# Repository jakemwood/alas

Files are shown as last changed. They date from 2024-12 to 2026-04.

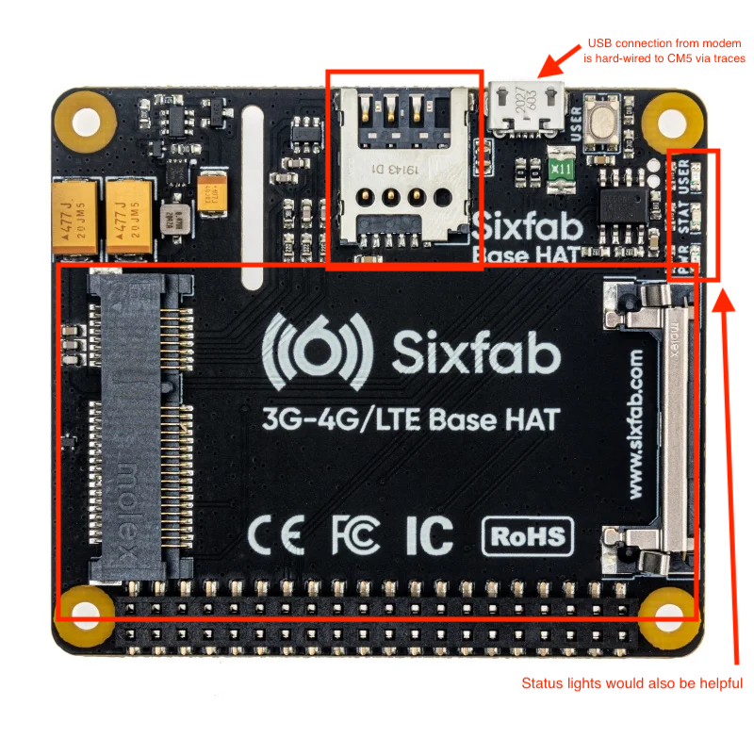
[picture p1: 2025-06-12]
cm5/docs/sixfab diagram.png

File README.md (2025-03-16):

<picture>
  <source media="(prefers-color-scheme: dark)" srcset="docs/logo-white.svg">
  alas logo
</picture>

# ALAS (Automatic Live Audio Streamer)

## Support / Donationware

Commercial support is available for purchase from Ridgeline Radio to support our non-commercial, non-profit radio station.

Stations with budgets over $100,000/year who use ALAS are encouraged to support the project in one of a few ways:

1. Buying the equipment from us
2. Paying monthly subscription fee for the bonded VPN
3. Buying a support package

## About ALAS

ALAS is a hardware/software appliance package that automatically streams and records audio with high reliability.
Whenever audio is present on the sound card input, ALAS will begin streaming and recording. If streaming should stop,
recording will continue, and vice versa. It achieves high straming reliability through the usage of a bonding VPN, with the
designs calling for both a cellular modem and usage of built-in WiFi. ALAS will discontinue streaming and recording after
a configurable period of silence.

## Project Navigation

### alas

The main application, written in Rust, which is deployed onto a Raspberry Pi. It is responsible for:

* Allowing for easy field configuration of the appliance via a WiFi access point
* Managing the WiFi state once configured by the end user
* Manging the cellular state once configured by the end user
* Continuously monitoring input audio signal to determine when audio is being input
* Stream audio to Icecast when audio is present
* Providing a web interface for end users to administer the device
* Ensuring audio traffic is using the appropriate Engarde Wireguard interface

### cad

You'll find FreeCAD and STEP files in this folder for fabricating the rack mountable case.

### docs

You'll find instructions on how to assemble the hardware and user's guide in this folder. Documentation for software
is generally found adjacent to these components.

### frontend

To save bandwidth, a static frontend is available with a configurable backend. The static frontend is found here.
This is distinct from the "deployed frontend," which is used during the initial configuration of the network settings
on the Raspberry Pi.

### infrastructure

This is the Terraform used to create the bonding VPN servers in Microsoft Azure. 

## ALAS Software Components

### alas_lib

alas_lib is meant to serve as the "brains" of the operation. However, there is some serious
separation of concerns issues here, as the main state of the application is actually held in `alas`.

### alas

This is the monolithic application that runs on the Raspberry Pi.

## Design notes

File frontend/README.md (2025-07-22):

# Frontend

This frontend is deployed to a static server (currently https://alas.krdf.org)

It was done this way so the frontend could be quickly loaded, and then only
minimal API payloads are shipped back and forth between the ALAS unit and
the browser.

## Deployment

Currently, deployment happens via git integration to Cloudflare pages.

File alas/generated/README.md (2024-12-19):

these files were generated by...

```shell
# on pi
busctl --system introspect org.freedesktop.NetworkManager /org/freedesktop/NetworkManager/Devices/1 --xml > out.xml
# copy out.xml to mac
scp ridgeline@ridgeline-live.local:/home/ridgeline/out.xml .
zbus-xmlgen file out.xml 
```

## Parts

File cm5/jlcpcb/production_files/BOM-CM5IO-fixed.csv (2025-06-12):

Comment | Designator | Footprint | LCSC | Quantity
2.2K 1% | R16 | R_0402_1005Metric | C114762 | 1
1k | R1,R10 | R_0402_1005Metric | C11702 | 2
LED Green | D2 | LED_0603_1608Metric | C12624 | 1
0.1uF | C1 | C_0603_1608Metric | C14663 | 1
4.7nF | C11 | C_0402_1005Metric | C1518204 | 1
100n | C10,C18,C26,C28,C30,C9 | C_0402_1005Metric | C1525 | 6
15pF | C31,C32 | C_0402 | C1548 | 2
10uF | C12,C13,C22,C23,C25,C27,C29 | C_0402 | C15525 | 7
10u | C14,C15,C16,C17,C2,C4,C6,C7,C8 | C_0805_2012Metric | C15850 | 9
33pF | C19,C20,C21,C5 | C_0603_1608Metric | C1663 | 4
USB3_A | J5 | C168717 | C168717 | 1
0R | R5 | R_0805_2012Metric_Pad1.20x1.40mm_HandSolder | C17477 | 1
0786463001 | J4 | MOLEX_0786463001 | C194938 | 1
AP3441SHE-7B | U8 | DFN-8-1EP_2x2mm_P0.5mm_EP1.05x1.75mm | C2070918 | 1
AP22653W6 | U6 | SOT-23-6 | C212302 | 1
15K | R19 | R_0603_1608Metric | C22809 | 1
LED Red | D1,D3,D6 | LED_0603_1608Metric | C2286 | 3
330 | R2,R3 | R_0603_1608Metric | C23138 | 2
22R | R13,R17,R18 | R_0603_1608Metric | C23345 | 3
15K 1% | R12 | R_0402_1005Metric | C269387 | 1
67910-5700 | J1 | MOLEX_67910-5700 | C277606 | 1
10K 1% | R15 | R_0402_1005Metric | C2906861 | 1
Conn_01x03 | J3,J6 | Molex_Micro-Fit_3.0_43650-0315_1x03_P3.00mm_Vertical | C293546 | 2
1x4 | J2,J7 | CONN_SD-43650-006_04_MOL 1x4 | C293547 | 2
Crystal (24.576MHz) | Y1 | S47SMD | C2975364 | 1
~ | MC1 | 480994000 | C492353 | 1
JST_SHBM04B-SRSS-TB | J14 | JST_SH_BM04B-SRSS-TB_1x04-1MP_P1.00mm_Vertical | C495539 | 1
74LVC1G07SE-7 | U5 | SOT-353_SC-70-5 | C5138996 | 1
2.2uH | L1 | L_Bourns_SRP7028A_7.3x6.6mm | C5189746 | 1
1uF | C24 | C_0402 | C52923 | 1
PCM1863DBT | U1 | DBT30_TEX | C529569 | 1
DALC208SC6 | CR1 | SOT23-6L | C54343 | 1
100K 1% | R14 | R_0402_1005Metric | C60491 | 1
ComputeModule5-CM5 | Module1 | Raspberry-Pi-5-Compute-Module | C6782225 | 2
100uF | C3 | CP_EIA-7343-31_Kemet-D | C72489 | 1

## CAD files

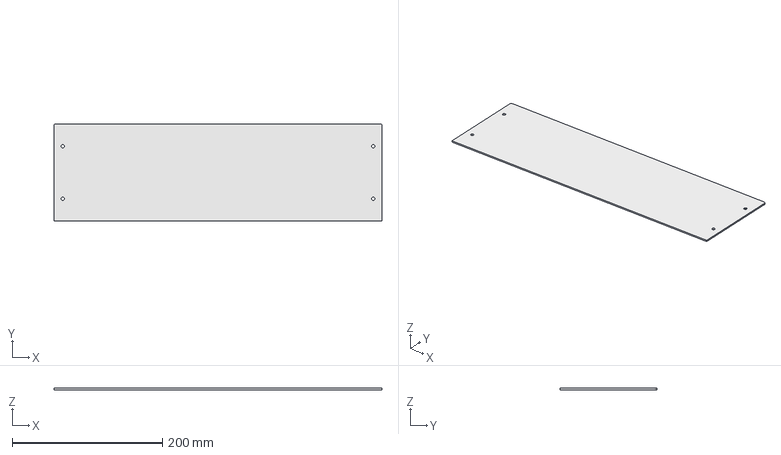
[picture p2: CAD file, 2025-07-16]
cad/Alas-Top.step
436.8 x 129.5 x 2.03 mm

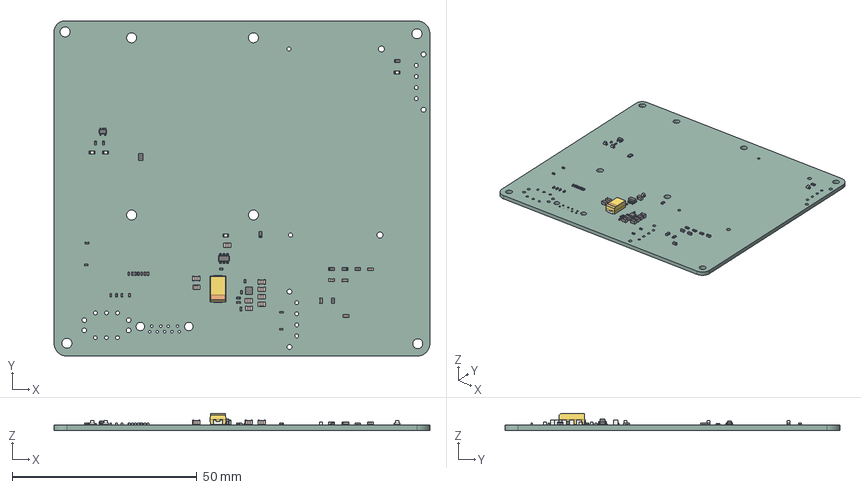
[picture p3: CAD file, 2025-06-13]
cm5/CM5IO.step
101.9 x 90.8 x 4.70 mm
R_0402_1005Metric x 6
LED_0603_1608Metric x 4
SOT-353_SC-70-5
R_0805_2012Metric
DFN-8-1EP_2x2mm_P0.5mm_EP1.05x1.75mm
C_0805_2012Metric x 9
C_0402_1005Metric x 4
C_0402 x 13
C_0603_1608Metric x 5
R_0603_1608Metric x 6
CP_EIA-7343-31_Kemet-D
SOT-23-6
CM5IO_PCB

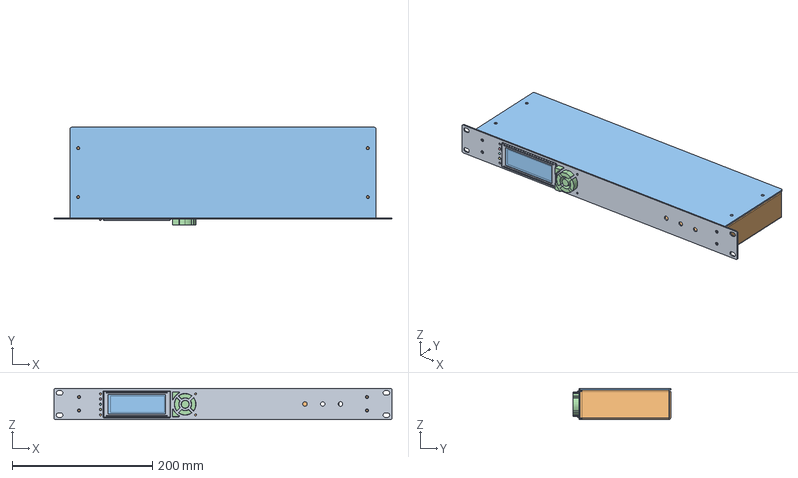
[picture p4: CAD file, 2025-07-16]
cad/Alas.FCStd
482.6 x 139.3 x 44.5 mm
Rack Face
Bottom
Top
GLK PCB_1
JUSBMB-V-TH_1
171825-4 (Alt Power)
Bezzel_1
Bezzel_002
Bezzel_003
2x12 RA Header_1
Glass_1
38mm 7T Keypad_1
LED_1
PCB_1
LED_002
LED_003
2x7 RA Header_1

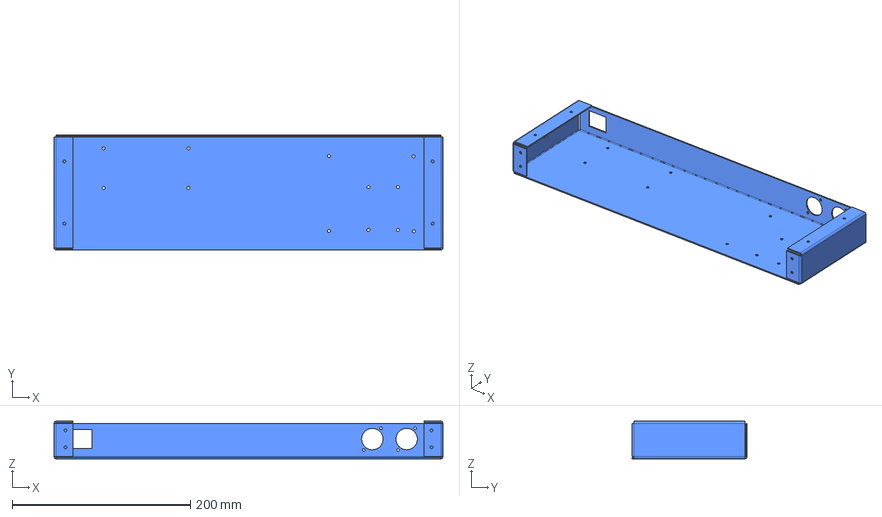
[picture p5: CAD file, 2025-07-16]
cad/Alas-Bottom.step
436.8 x 129.5 x 42.4 mm

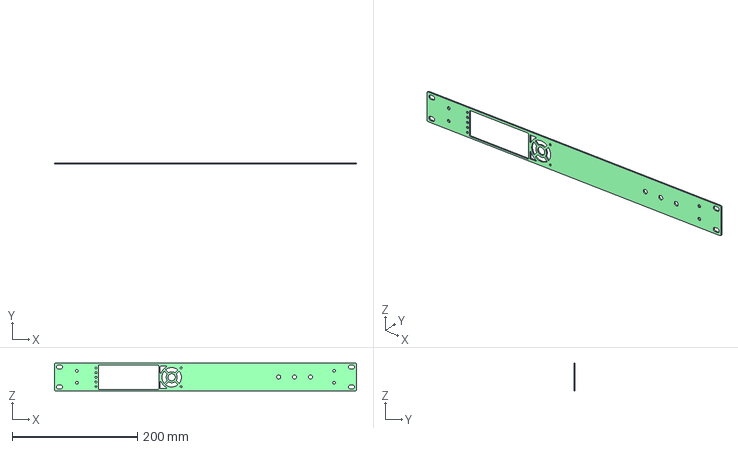
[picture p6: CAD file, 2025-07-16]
cad/Alas-Rack Face.step
482.6 x 1.88 x 44.5 mm

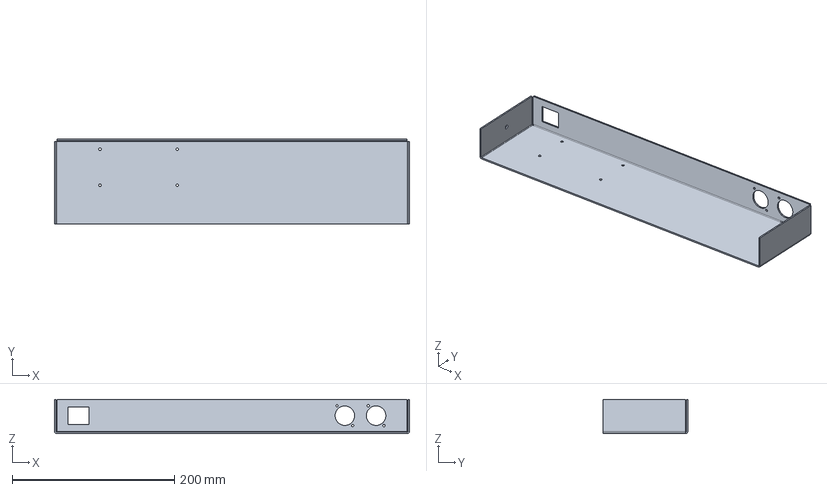
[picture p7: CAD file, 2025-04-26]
cad/New Top.FCStd
437.5 x 104.5 x 42.4 mm

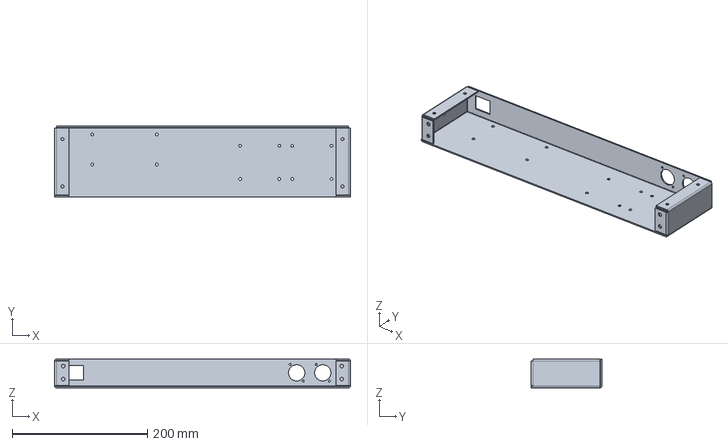
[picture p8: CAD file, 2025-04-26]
cad/Multipart - Flat.FCStd
437.1 x 104.2 x 42.4 mm

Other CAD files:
cad/v0.FCStd

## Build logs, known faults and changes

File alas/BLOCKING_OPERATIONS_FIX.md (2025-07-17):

# Blocking Operations Fix Analysis

## Issue Fixed
The ALSA POLLERR when running both `start_icecast_thread` and `start_file_save_thread` was caused by blocking operations in the audio callback (`handle_samples` function).

## Root Cause
Audio callbacks must be real-time safe and cannot block. The following blocking operations in `handle_samples` were causing ALSA timeouts:
- `state.blocking_read().clone()` at line ~420
- `state.blocking_write()` at lines ~432 and ~445

## Applied Fix
Replaced blocking operations with non-blocking alternatives:

```rust
// Before:
let read_state = {
    state.blocking_read().clone()
};

// After:
let read_state = match state.try_read() {
    Ok(guard) => guard.clone(),
    Err(_) => return, // Skip if can't acquire lock
};

// Before:
let mut state = state.blocking_write();
(*state).is_audio_present = true;

// After:
if let Ok(mut state) = state.try_write() {
    (*state).is_audio_present = true;
}
```

## Remaining Blocking Operations
Found 6 additional blocking operations in the Icecast thread that could be optimized:

### 1. Streaming Status Updates (lines 282-289)
```rust
// Current:
if !state.blocking_read().is_streaming {
    let mut mutable_state = state.blocking_write();
    mutable_state.is_streaming = true;
    let _ = message_bus.send(AlasMessage::StreamingStarted);
}

// Suggested fix:
if let Ok(read_state) = state.try_read() {
    if !read_state.is_streaming {
        drop(read_state);
        if let Ok(mut mutable_state) = state.try_write() {
            mutable_state.is_streaming = true;
            let _ = message_bus.send(AlasMessage::StreamingStarted);
        }
    }
}
```

### 2. Error Handling (lines 289-292)
```rust
// Current:
let mut mutable_state = state.blocking_write();
mutable_state.is_streaming = false;
let _ = message_bus.send(AlasMessage::StreamingStopped);

// Suggested fix:
if let Ok(mut mutable_state) = state.try_write() {
    mutable_state.is_streaming = false;
    let _ = message_bus.send(AlasMessage::StreamingStopped);
}
```

### 3. Loop Cleanup (lines 312-315)
```rust
// Current:
let mut mutable_state = state.blocking_write();
mutable_state.is_streaming = false;
let _ = message_bus.send(AlasMessage::StreamingStopped);

// Suggested fix:
if let Ok(mut mutable_state) = state.try_write() {
    mutable_state.is_streaming = false;
    let _ = message_bus.send(AlasMessage::StreamingStopped);
}
```

### 4. Thread Exit Cleanup (lines 320-322)
```rust
// Current:
let mut mutable_state = state.blocking_write();
mutable_state.is_streaming = false;
let _ = message_bus.send(AlasMessage::StreamingStopped);

// Suggested fix:
if let Ok(mut mutable_state) = state.try_write() {
    mutable_state.is_streaming = false;
    let _ = message_bus.send(AlasMessage::StreamingStopped);
}
```

### 5. Icecast Connection Setup (line 372)
```rust
// Current:
let state = state.blocking_read();

// Suggested fix:
let state = match state.try_read() {
    Ok(guard) => guard,
    Err(_) => {
        std::thread::sleep(std::time::Duration::from_millis(10));
        continue; // Retry connection attempt
    }
};
```

## Priority
- **Critical (FIXED)**: Audio callback blocking operations - these caused the ALSA POLLERR
- **Medium**: Icecast thread blocking operations - these could cause lock contention but are less critical

## Notes
The audio callback fix was essential for real-time audio processing. The remaining fixes are optimizations that would improve overall system responsiveness but are not critical for basic functionality.

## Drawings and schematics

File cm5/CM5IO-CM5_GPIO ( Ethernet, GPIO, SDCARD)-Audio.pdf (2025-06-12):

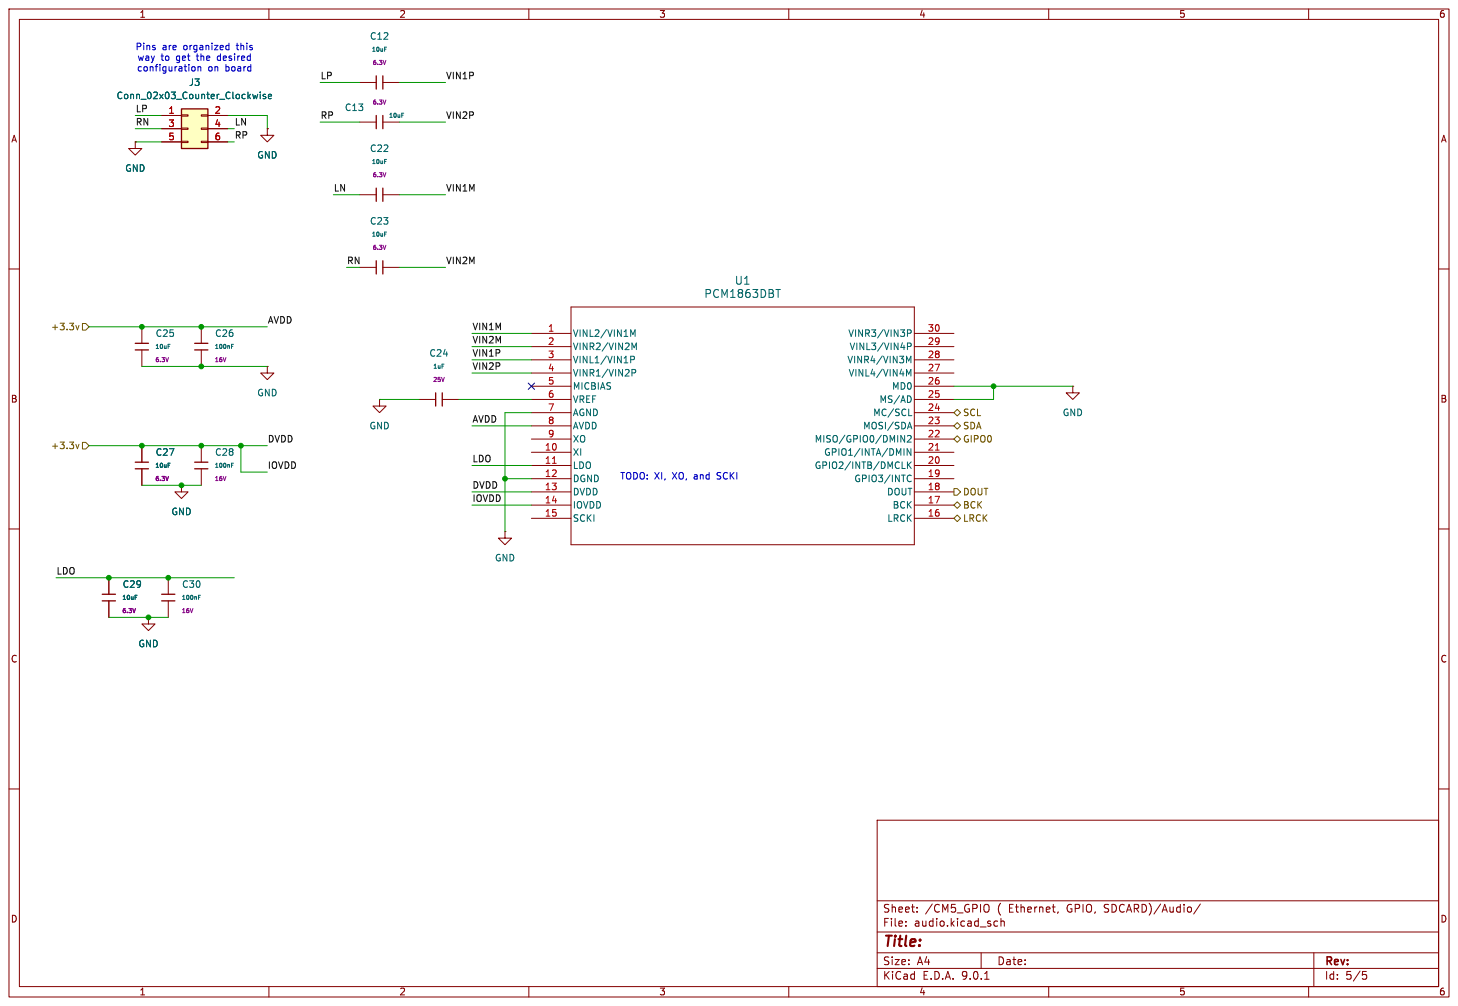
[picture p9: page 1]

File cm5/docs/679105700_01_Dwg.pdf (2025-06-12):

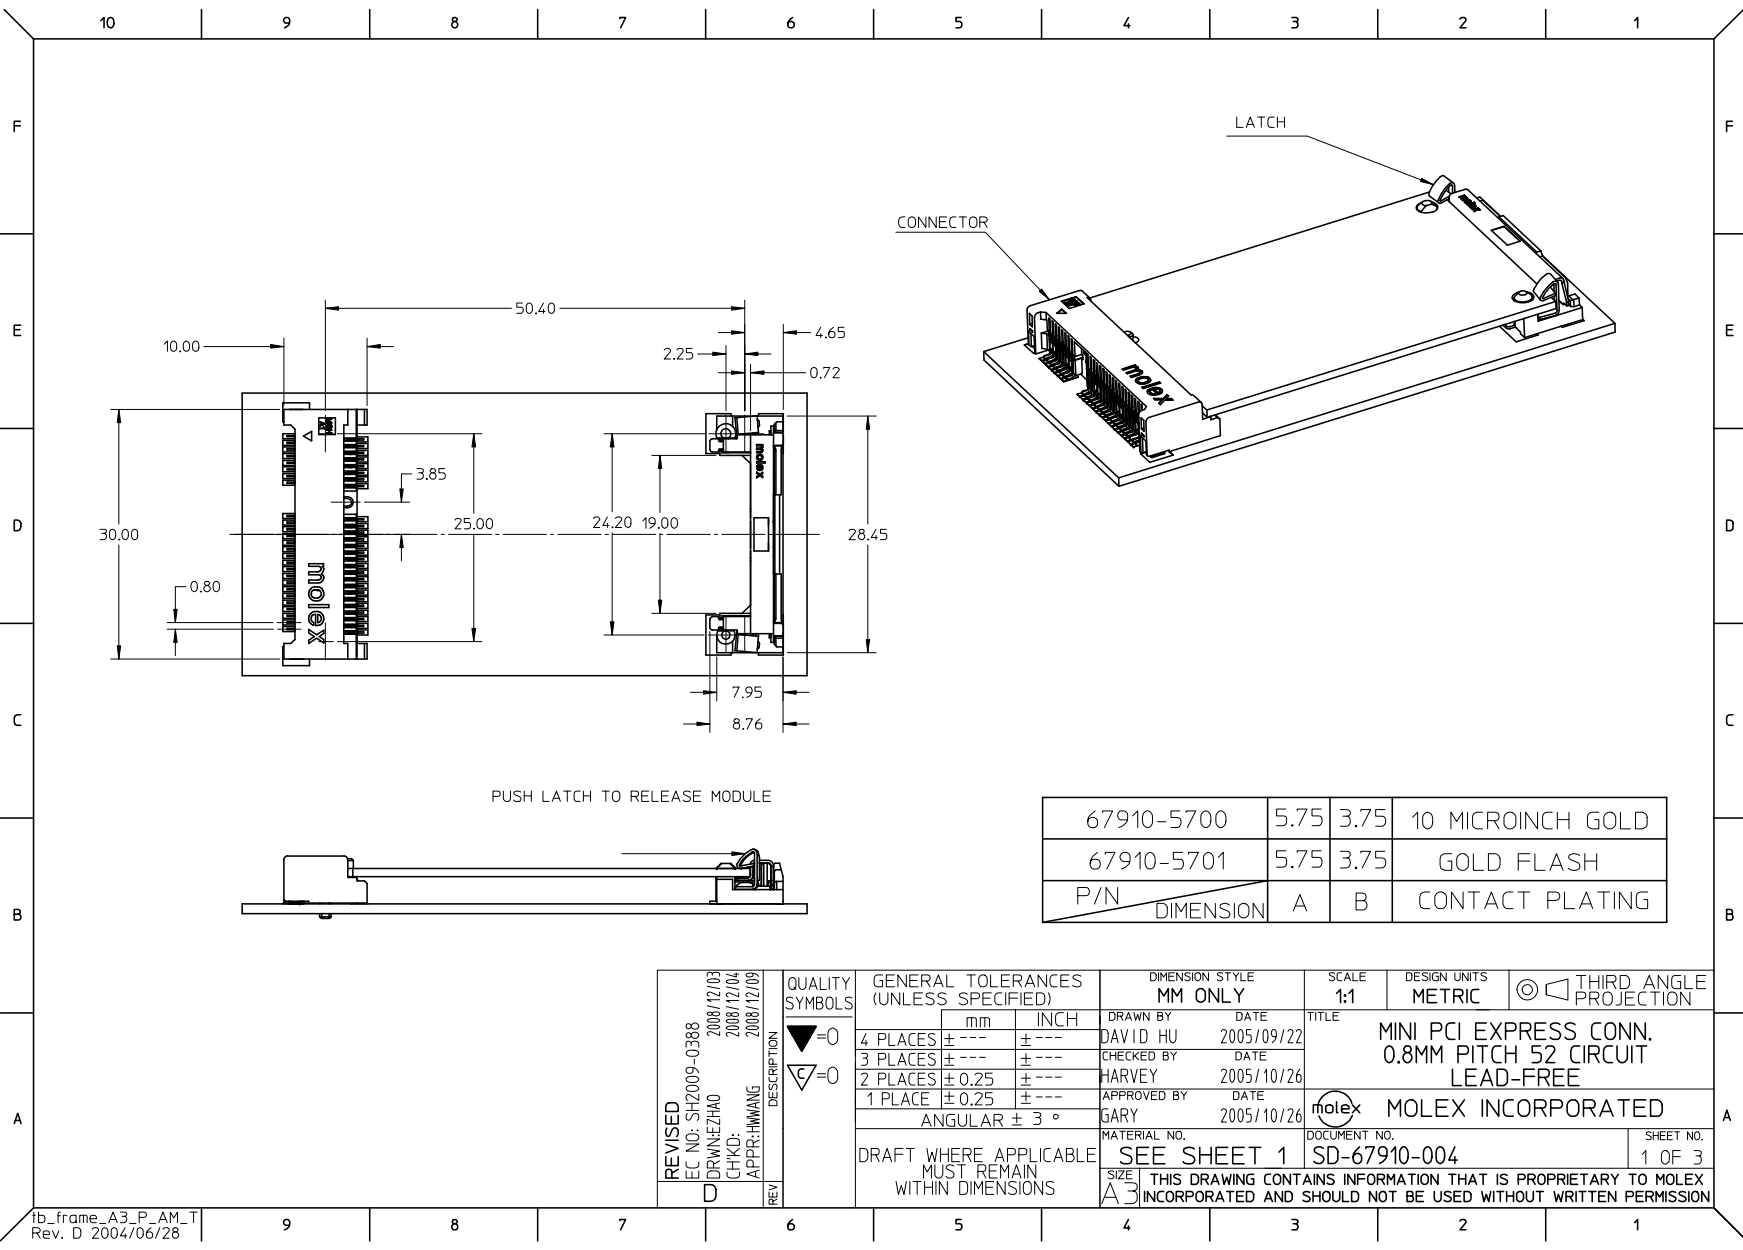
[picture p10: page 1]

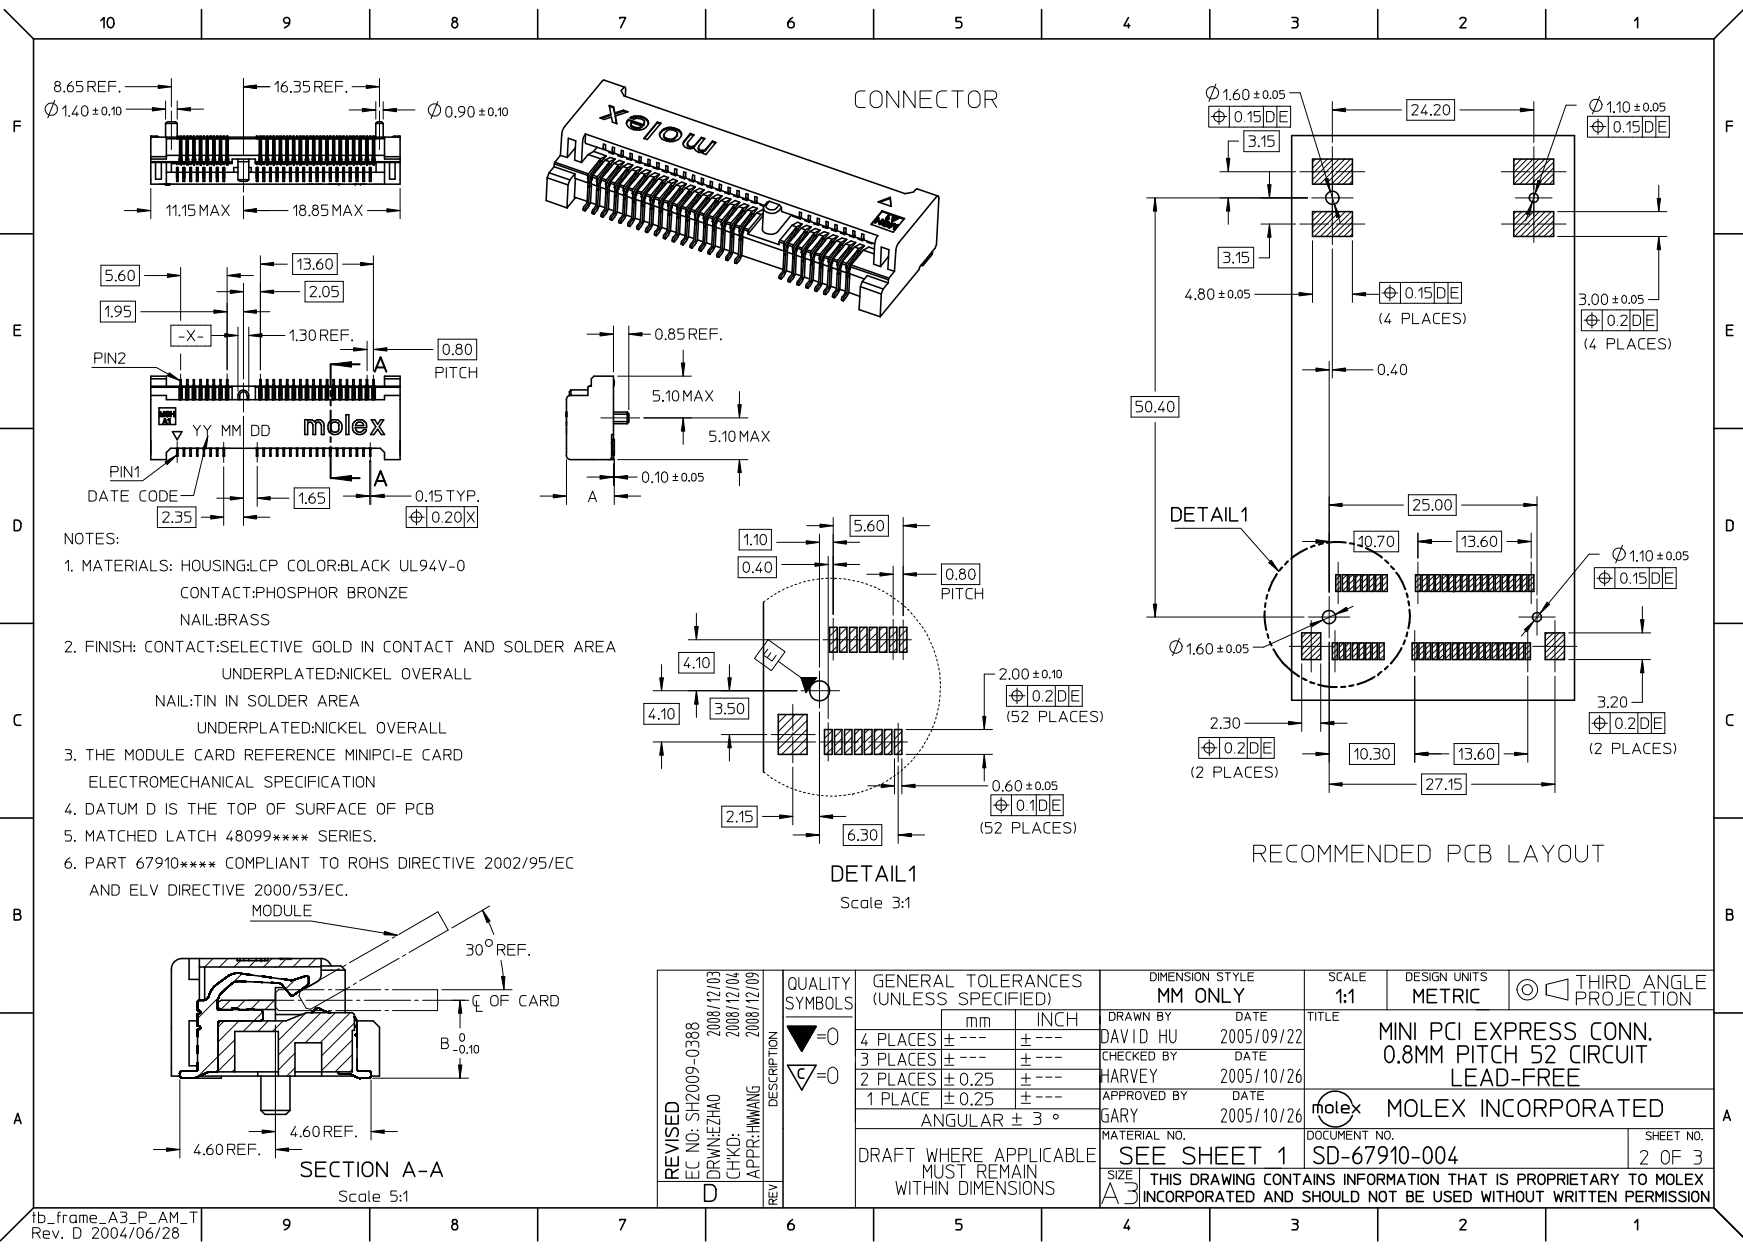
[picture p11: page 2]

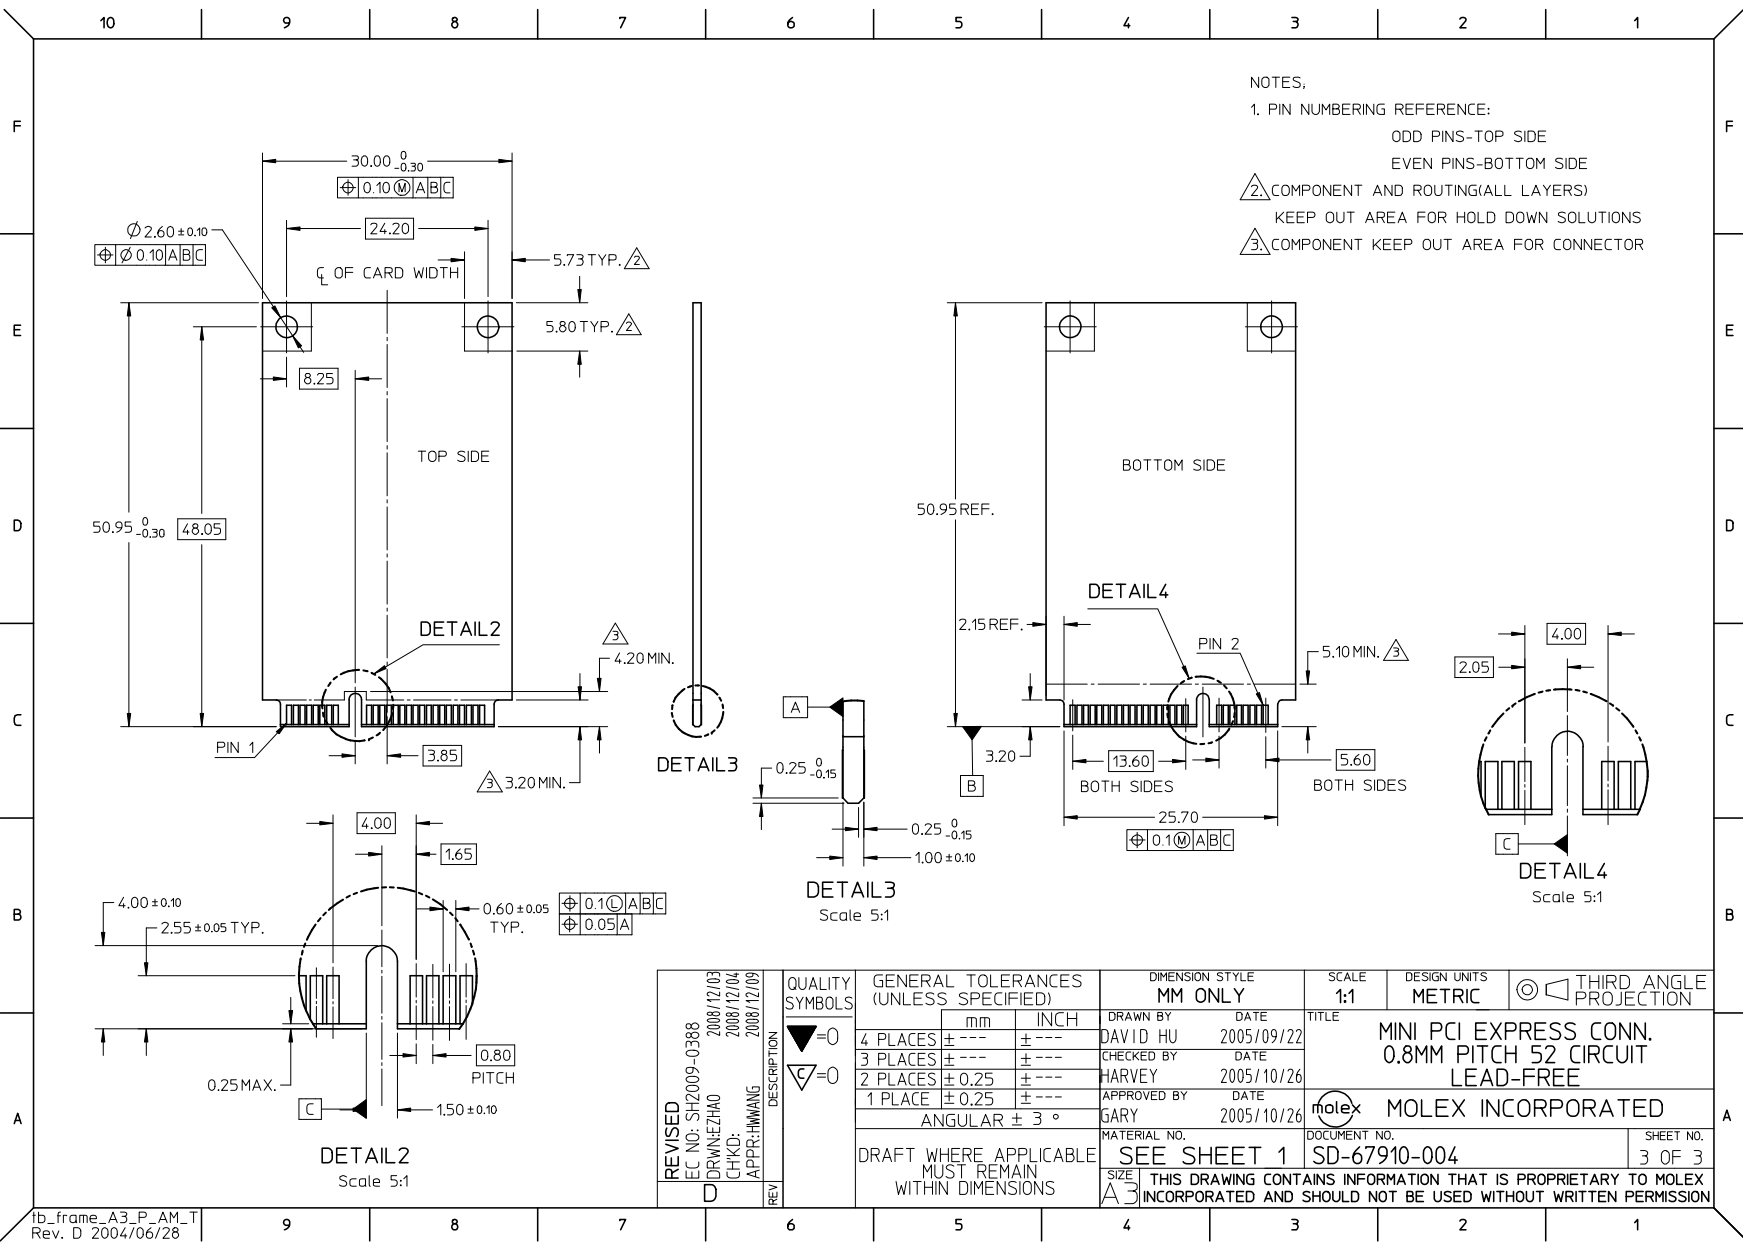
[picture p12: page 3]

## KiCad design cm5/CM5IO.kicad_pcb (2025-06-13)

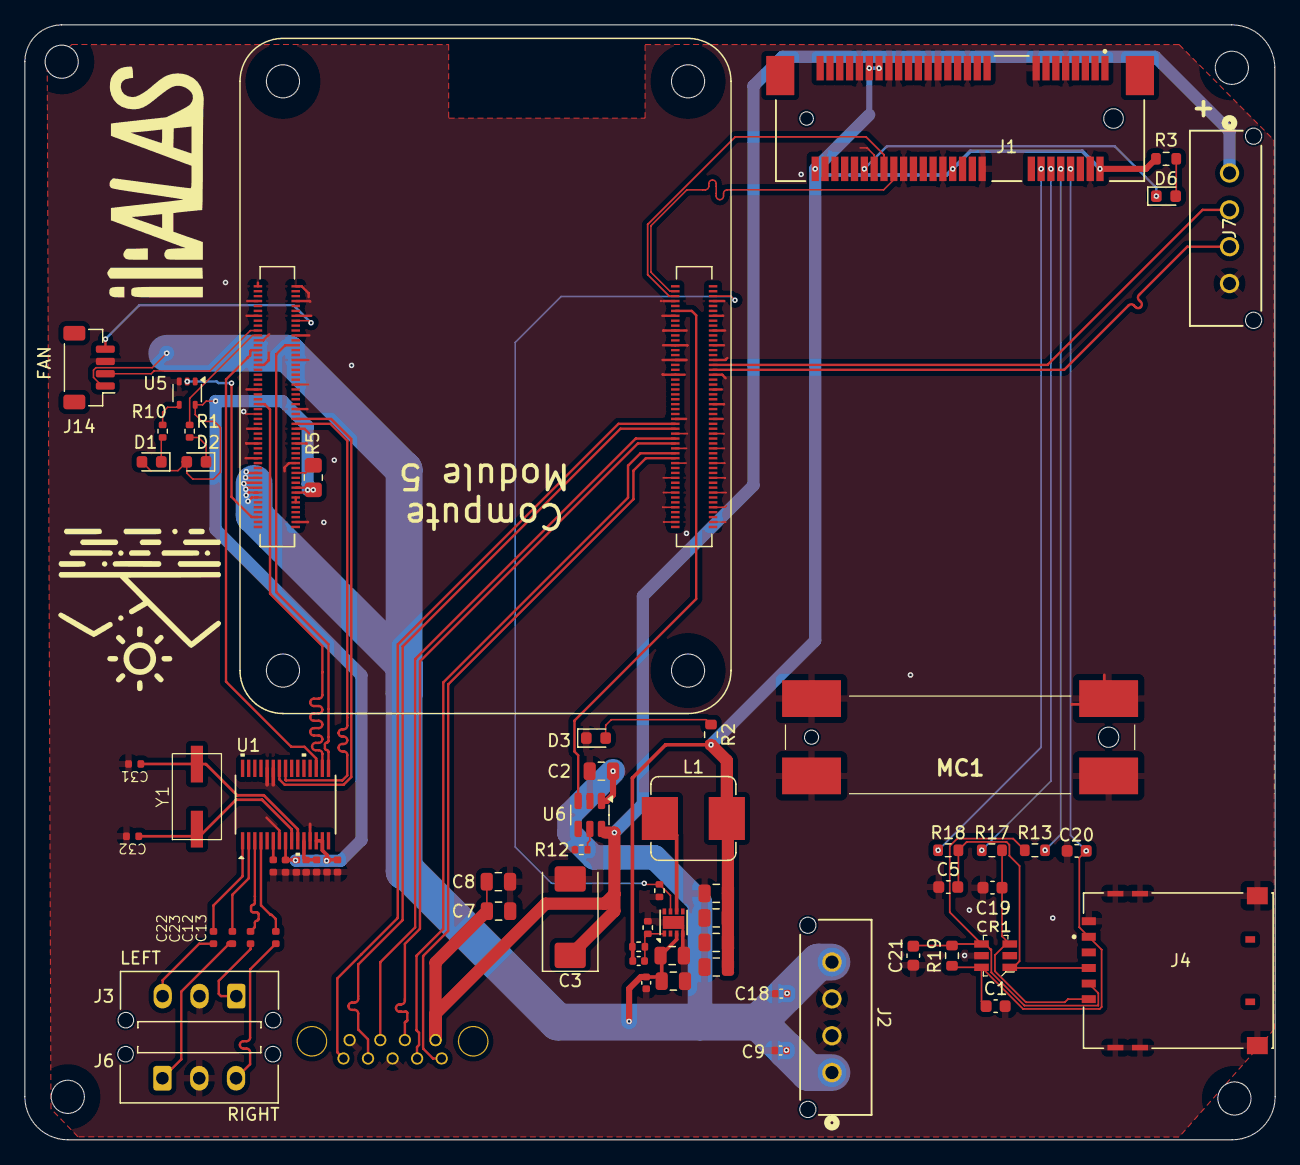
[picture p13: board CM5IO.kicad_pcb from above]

Board: 4 copper layers, 101.9 x 90.8 mm, 70 parts (0 on the bottom side), 56 nets.

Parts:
C1: 0.1uF; C_0603_1608Metric
C2, C4, C6, C7, C8, C14, C15, C16, C17: 10u; C_0805_2012Metric
C3: 100uF; CP_EIA-7343-31_Kemet-D
C5, C19, C20, C21: 33pF; C_0603_1608Metric
C9, C10, C18: 100n; C_0402_1005Metric
C11: 4.7nF; C_0402_1005Metric
C12, C13, C22, C23, C25, C27, C29: 10uF; C_0402
C24: 1uF; C_0402
C26, C28, C30: 100nF; C_0402
C31, C32: 15pF; C_0402
CR1: DALC208SC6; SOT23-6L
D1, D3, D6: LED Red; LED_0603_1608Metric
D2: LED Green; LED_0603_1608Metric
H2, H3, H6, H8: MountingHole; MountingHole_2.7mm_M2.5_DIN965
J1: 67910-5700; MOLEX_67910-5700
J2: 1x4; CONN_SD-43650-006_04_MOL 1x4
J3, J6: Conn_01x03; Molex_Micro-Fit_3.0_43650-0315_1x03_P3.00mm_Vertical
J4: 0786463001; MOLEX_0786463001
J5: USB3_A; C168717
J7: Conn_01x04; CONN_SD-43650-006_04_MOL 1x4
J14: JST_SHBM04B-SRSS-TB; JST_SH_BM04B-SRSS-TB_1x04-1MP_P1.00mm_Vertical
L1: 2.2uH; L_Bourns_SRP7028A_7.3x6.6mm
MC1: 480994000
Module1: ComputeModule5-CM5; Raspberry-Pi-5-Compute-Module
R1, R10: 1k; R_0402_1005Metric
R2, R3: 330; R_0603_1608Metric
R5: 0R; R_0805_2012Metric_Pad1.20x1.40mm_HandSolder
R12: 15K 1%; R_0402_1005Metric
R13, R17, R18: 22R; R_0603_1608Metric
R14: 100K 1%; R_0402_1005Metric
R15: 10K 1%; R_0402_1005Metric
R16: 2.2K 1%; R_0402_1005Metric
R19: 15K; R_0603_1608Metric
U1: PCM1863DBT; DBT30_TEX
U5: 74LVC1G07SE-7; SOT-353_SC-70-5
U6: AP22653W6; SOT-23-6
U8: AP3441SHE-7B; DFN-8-1EP_2x2mm_P0.5mm_EP1.05x1.75mm
Y1: Crystal (24.576MHz); S47SMD

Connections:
/+3.3v: C25.2, C26.2, C27.2, C28.1, D1.2 (A), D2.2 (A), Module1.84 (+3.3v_(Output)), Module1.86 (+3.3v_(Output)), R5.1, U1.8 (AVDD), U1.13 (DVDD), U1.14 (IOVDD), U5.5 (VCC)
/+5v: C2.1, C4.1, C6.1, C9.1, C10.1, C18.1, J2.1, J2.4, J14.1, Module1.77 (+5v_(Input)), Module1.79 (+5v_(Input)), Module1.81 (+5v_(Input)), Module1.83 (+5v_(Input)), Module1.85 (+5v_(Input)), Module1.87 (+5v_(Input)), U6.1 (IN), U8.3 (VIN)
/CM5_GPIO ( Ethernet, GPIO, SDCARD)/+1.8v: Module1.88 (+1.8v_(Output)), Module1.90 (+1.8v_(Output))
/CM5_GPIO ( Ethernet, GPIO, SDCARD)/Audio/LDO: C29.2, C30.1, U1.11 (LDO)
/CM5_GPIO ( Ethernet, GPIO, SDCARD)/Audio/LN: C22.1, J3.3
/CM5_GPIO ( Ethernet, GPIO, SDCARD)/Audio/LP: C12.1, J3.1
/CM5_GPIO ( Ethernet, GPIO, SDCARD)/Audio/RN: C23.1, J6.1
/CM5_GPIO ( Ethernet, GPIO, SDCARD)/Audio/RP: C13.1, J6.3
/CM5_GPIO ( Ethernet, GPIO, SDCARD)/Audio/VIN1M: C22.2, U1.1 (VINL2/VIN1M)
/CM5_GPIO ( Ethernet, GPIO, SDCARD)/Audio/VIN1P: C12.2, U1.3 (VINL1/VIN1P)
/CM5_GPIO ( Ethernet, GPIO, SDCARD)/Audio/VIN2M: C23.2, U1.2 (VINR2/VIN2M)
/CM5_GPIO ( Ethernet, GPIO, SDCARD)/Audio/VIN2P: C13.2, U1.4 (VINR1/VIN2P)
/CM5_GPIO ( Ethernet, GPIO, SDCARD)/Audio/XI: C31.1, U1.10 (XI), Y1.2
/CM5_GPIO ( Ethernet, GPIO, SDCARD)/Audio/XO: C32.1, U1.9 (XO), Y1.1
/CM5_GPIO ( Ethernet, GPIO, SDCARD)/GPIO2: Module1.58 (GPIO2), U1.23 (MOSI/SDA)
/CM5_GPIO ( Ethernet, GPIO, SDCARD)/GPIO3: Module1.56 (GPIO3), U1.24 (MC/SCL)
/CM5_GPIO ( Ethernet, GPIO, SDCARD)/GPIO18: Module1.49 (GPIO18), U1.17 (BCK)
/CM5_GPIO ( Ethernet, GPIO, SDCARD)/GPIO19: Module1.26 (GPIO19), U1.16 (LRCK)
/CM5_GPIO ( Ethernet, GPIO, SDCARD)/GPIO20: Module1.27 (GPIO20), U1.18 (DOUT)
/CM5_GPIO ( Ethernet, GPIO, SDCARD)/GPIO_VREF: Module1.78 (GPIO_VREF(1.8v/3.3v_Input)), R5.2
/CM5_GPIO ( Ethernet, GPIO, SDCARD)/PWM: J14.2, Module1.19 (FAN_PWM)
/CM5_GPIO ( Ethernet, GPIO, SDCARD)/TACHO: J14.4, Module1.16 (FAN_TACHO)
/CM5_GPIO ( Ethernet, GPIO, SDCARD)/nPWR_LED: Module1.95 (LED_nPWR), U5.2
/CM5_HighSpeed/PCIE_PWR_EN: Module1.106 (PCIE_PWR_EN), R14.1, U8.7 (EN)
/CM5_HighSpeed/USB2_N: J1.36, Module1.103 (USB2_N)
/CM5_HighSpeed/USB2_P: J1.38, Module1.105 (USB2_P)
/CM5_HighSpeed/USB3-0-D_N: J7.3, Module1.136 (USB3-0-D_N)
/CM5_HighSpeed/USB3-0-D_P: J7.2, Module1.134 (USB3-0-D_P)
/CM5_HighSpeed/USB3-1-D_N: J5.2 (D-), Module1.165 (USB3-1-D_N)
/CM5_HighSpeed/USB3-1-D_P: J5.3 (D+), Module1.163 (USB3-1-D_P)
/CM5_HighSpeed/USB3-1-RX_N: J5.5 (SSRX-), Module1.157 (USB3-1-RX_N)
/CM5_HighSpeed/USB3-1-RX_P: J5.6 (SSRX+), Module1.159 (USB3-1-RX_P)
/CM5_HighSpeed/USB3-1-TX_N: J5.8 (SSTX-), Module1.169 (USB3-1-TX_N)
/CM5_HighSpeed/USB3-1-TX_P: J5.9 (SSTX+), Module1.171 (USB3-1-TX_P)
/CM5_HighSpeed/VBUS: C3.1, C7.1, C8.1, J5.1 (VBUS), J7.1, U6.6 (OUT)
/CM5_HighSpeed/VBUS_EN: Module1.111 (VBUS_EN), U6.3 (EN)
/Cellular/FB: C11.2, R15.2, R16.1, U8.1 (FB)
/Cellular/LED_WWAN: D6.1 (K), J1.42
/Cellular/M2_3v3: C11.1, C14.1, C15.1, C16.1, C17.1, J1.2, J1.24, J1.39, J1.41, J1.52, L1.2, R2.2, R3.2, R15.1
/Cellular/SIM_CLK: J1.12, R17.1
/Cellular/SIM_DATA: J1.10, R13.2
/Cellular/SIM_RST: J1.14, R18.1
/Cellular/SIM_VDD: C1.1, C20.1, CR1.6 (I/O4), J1.8, J4.C1 (VCC), R19.1
GND: C1.2, C2.2, C3.2, C4.2, C5.1, C6.2, C7.2, C8.2, C9.2, C10.2, C14.2, C15.2, C16.2, C17.2, C18.2, C19.1, C20.2, C21.2, C24.1, C25.1, C26.1, C27.1, C28.2, C29.1, C30.2, C31.2, C32.2, CR1.5 (REF1), D3.1 (K), J1.4, J1.9, J1.15, J1.18, J1.21, J1.26, J1.27, J1.29, J1.34, J1.35, J1.37, J1.40, J1.43, J1.50, J2.2, J2.3, J3.2, J4.C5 (GND), J4.G1 (GND__1), J4.G2 (GND__2), J4.G3 (GND__3), J4.G4 (GND__4), J4.G5 (GND__5), J4.G6 (GND__6), J5.4 (GND), J5.7 (DRAIN), J6.2, J7.4, J14.3, MC1.1, MC1.2, MC1.3, MC1.4, Module1.1 (GND), Module1.2 (GND), Module1.7 (GND), Module1.8 (GND), Module1.13 (GND), Module1.14 (GND), Module1.22 (GND), Module1.23 (GND), Module1.32 (GND), Module1.33 (GND), Module1.42 (GND), Module1.43 (GND), Module1.52 (GND), Module1.53 (GND), Module1.59 (GND), Module1.60 (GND), Module1.65 (GND), Module1.66 (GND), Module1.71 (GND), Module1.74 (GND), Module1.98 (GND), Module1.107 (GND), Module1.108 (GND), Module1.113 (GND), Module1.114 (GND), Module1.119 (GND), Module1.120 (GND), Module1.125 (GND), Module1.126 (GND), Module1.131 (GND), Module1.132 (GND), Module1.137 (GND), Module1.138 (GND), Module1.144 (GND), Module1.150 (GND), Module1.155 (GND), Module1.156 (GND), Module1.161 (GND), Module1.162 (GND), Module1.167 (GND), Module1.168 (GND), Module1.173 (GND), Module1.174 (GND), Module1.179 (GND), Module1.180 (GND), Module1.185 (GND), Module1.186 (GND), Module1.191 (GND), Module1.192 (GND), Module1.197 (GND), Module1.198 (GND), R12.2, R14.2, R16.2, U1.7 (AGND), U1.12 (DGND), U1.25 (MS/AD), U1.26 (MD0), U5.3 (GND), U6.2 (GND), U8.4 (PGND), U8.8 (SGND), U8.9 (PAD)
unnamed: C5.2, CR1.1 (I/O1), J4.C2 (RST), R18.2
unnamed: C19.2, CR1.3 (I/O2), J4.C3 (CLK), R17.2
unnamed: C21.1, CR1.4 (I/O3), J4.C7 (I/O), R13.1, R19.2
unnamed: D1.1 (K), R10.1
unnamed: D2.1 (K), R1.1
unnamed: D3.2 (A), R2.1
unnamed: D6.2 (A), R3.1
unnamed: Module1.21 (LED_nACT), R1.2
unnamed: R10.2, U5.4
unnamed: C24.2, U1.6 (VREF)
unnamed: R12.1, U6.5 (ILIM)
unnamed: L1.1, U8.6 (LX)

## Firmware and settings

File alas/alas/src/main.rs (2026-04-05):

mod lcd_display;
mod web_server;

use alas_lib::state::AlasMessage;
use alas_lib::state::AlasState;
use alas_lib::webhook::start_webhook_listener;
use alas_lib::wifi::{ WiFiObserver };
use alas_lib::cellular::{ CellObserver };
use alas_lib::redundancy;
use serialport::SerialPort;
use std::io::Write;
use std::sync::Arc;
use tokio;
use tokio::signal;
use tokio::sync::{ broadcast, RwLock };

#[tokio::main]
async fn main() {
    // TODO: this was originally designed to be Redux-like but then it turned evil. Refactor.
    let state = Arc::new(RwLock::new(AlasState::new()));
    let (event_bus, _) = broadcast::channel::<AlasMessage>(256);

    // Conditionally initialize redundancy manager and WireGuard interface
    let _redundancy_manager = if state.read().await.config.redundancy.is_some() {
        let manager = redundancy::RedundancyManager::new();
        if let Err(e) = manager.initialize(&state).await {
            eprintln!("Failed to initialize redundancy manager: {}", e);
        }
        if let Err(e) = manager.start_wireguard_interface().await {
            eprintln!("Failed to start WireGuard interface: {}", e);
        }
        Some(manager)
    } else {
        println!("ℹ️  Redundancy not configured");
        None
    };

    let lcd_thread = lcd_display::start(event_bus.clone(), &state).await;

    // Conditionally start cellular observer
    let cell_changes = if state.read().await.config.cellular.is_some() {
        let cell_observer = Arc::new(CellObserver::new(event_bus.clone(), &state));
        Some(cell_observer.listen().await)
    } else {
        println!("ℹ️  Cellular not configured");
        None
    };

    // WiFi observer always runs (needed for config hotspot mode)
    let wifi_observer = Arc::new(WiFiObserver::new(event_bus.clone(), &state));
    let wifi_changes = wifi_observer.listen();

    let audio = alas_lib::audio::start(event_bus.clone(), &state).await;
    println!("Audio results are: {:?}", audio);

    // Start webhook listener
    start_webhook_listener(event_bus.subscribe(), state.clone()).await;

    let web_server = web_server::run_rocket_server(event_bus.clone(), &state).await;

    // Wait for exit here! All code below is for clean-up!

    signal::ctrl_c().await.expect("failed to listen for event");
    let _ = event_bus.send(AlasMessage::Exit);

    // Await all of our "threads" here to clean up...
    println!("Waiting for Wi-Fi to unwrap...");
    wifi_changes.await.expect("WiFi thread failed");

    if let Some(cell_changes) = cell_changes {
        println!("Waiting for cellular to unwrap...");
        let _ = cell_changes.await;
    }

    // LCD should always be last to exit so that we can display all messages
    println!("Waiting for web server to await...");
    web_server.await.expect("Oh well 3");
    println!("Waiting for lcd to unwrap...");
    lcd_thread.await.expect("Oh well 4");
    println!("Waiting for audio to unwrap...");
    let audio_threads = audio.await.expect("Audio thread failed");
    println!("Waiting for config thread to unwrap...");
    let result_one = audio_threads.config_thread.await.unwrap();
    println!("Results: {:?}", result_one);

    if let Some(icecast) = audio_threads.icecast {
        println!("Waiting for Icecast to unwrap...");
        let result_two = icecast.await.unwrap();
        println!("Icecast unwrapped: {:?}", result_two);
    }

    if let Some(recording) = audio_threads.recording {
        println!("Waiting for recording to unwrap...");
        let recording_result = recording.await.unwrap();
        println!("Recording result: {:?}", recording_result);
    }
}

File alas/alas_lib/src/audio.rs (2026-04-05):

use cpal::traits::{DeviceTrait, HostTrait, StreamTrait };
use cpal::{BufferSize, Sample, StreamConfig};
use mp3lame_encoder::{ DualPcm, Encoder, FlushNoGap };
use shout::{ ShoutConn };
use std::fs::File;
use std::io::Write;
use std::sync::atomic::{ AtomicBool, Ordering };
use std::sync::Arc;
use std::time::{ SystemTime, UNIX_EPOCH };
use tokio::runtime::Handle;
use tokio::sync::broadcast::Sender;

use crate::state::AlasMessage::VolumeChange;
use crate::state::{ AlasMessage, AlasState, SafeState };
use bus::{Bus, BusReader};
use tokio::task::JoinHandle;
use tokio::{ select, task };
use tokio::sync::RwLock;
use crate::dropbox::upload_file_to_dropbox;

#[derive(Debug)]
pub struct AudioThreads {
    pub config_thread: JoinHandle<()>,
    pub icecast: Option<JoinHandle<&'static str>>,
    pub recording: Option<JoinHandle<&'static str>>,
}

/// Starts the thread for handling audio.
///
/// This closure will hold the state for all things related to audio, including
/// if there is currently audio flowing through the system, how long it has been
/// silent, etc. It will also start and stop the Icecast thread based on these
/// times.
pub async fn start(
    bus: Sender<AlasMessage>,
    alas_state: &SafeState
) -> JoinHandle<AudioThreads> {
    let handler = Handle::current();
    let alas_state = alas_state.clone();

    task::spawn_blocking(move || {
        let mut desire_to_broadcast = Arc::new(AtomicBool::new(false));
        let config_reset = Arc::new(AtomicBool::new(false));
        let mut audio_last_seen = UNIX_EPOCH;

        // Check which services are enabled
        let enabled = alas_state.blocking_read().config.enabled_services();
        let num_consumers = (enabled.recording as usize) + (enabled.streaming as usize);

        let mut audio_bus = if num_consumers > 0 {
            Some(Bus::<Vec<f32>>::new(2204 * 30))
        } else {
            println!("ℹ️  No audio consumers configured, audio processing disabled");
            None
        };

        // Config watch
        let mut subscriber = bus.subscribe();
        let config_reset_watch = config_reset.clone();
        let config_thread = task::spawn(async move {
            loop {
                let msg = subscriber.recv().await;
                if let Ok(msg) = msg {
                    match msg {
                        AlasMessage::StreamingConfigUpdated => {
                            // Switch off the desire to broadcast to kill the loop
                            config_reset_watch.store(true, Ordering::Relaxed);
                        }
                        AlasMessage::Exit => {
                            println!("✅ Exiting config thread!");
                            return;
                        }
                        _ => {}
                    }
                } else {
                    println!("❌ Exiting config loop on an error");
                    break;
                }
            }
            println!("✅ Exited config thread");
        });

        // Conditionally spawn Icecast streaming thread
        let icecast = if enabled.streaming {
            if let Some(ref mut audio_bus_ref) = audio_bus {
                let icecast_rx = audio_bus_ref.add_rx();
                Some(start_icecast_thread(
                    icecast_rx,
                    desire_to_broadcast.clone(),
                    alas_state.clone(),
                    bus.clone(),
                    config_reset.clone()
                ))
            } else {
                None
            }
        } else {
            println!("ℹ️  Icecast not configured, streaming disabled");
            None
        };

        // Conditionally spawn file saving thread
        let record = if enabled.recording {
            if let Some(ref mut audio_bus_ref) = audio_bus {
                let file_rx = audio_bus_ref.add_rx();
                Some(start_file_save_thread(
                    file_rx,
                    desire_to_broadcast.clone(),
                    bus.clone()
                ))
            } else {
                None
            }
        } else {
            println!("ℹ️  Recording not configured, recording disabled");
            None
        };

        let host = cpal::default_host();

        // host.input_devices().expect("No input devices").for_each(|device| {
        //     let name = device.name().unwrap_or_else(|_| "Unknown".to_string());
        //     println!("🔈 Found device: {}", name);
        // });

        let device = host.input_devices()
            .expect("No input devices")
            .find(|device| {
                let name = device.name().unwrap_or_else(|_| "Unknown".to_string());
                name.contains("PCM1863") && name.contains("plughw:")
            })
            .expect("No device found containing 'PCM1863'");

        let err_fn = move |err| {
            eprintln!("an error occurred on stream: {}", err);
        };

        let mut exit_bus = bus.subscribe();

        let stream_config = StreamConfig {
            channels: 2,
            sample_rate: cpal::SampleRate(48_000),
            buffer_size: BufferSize::Default,
        };
        let stream = match device
            .build_input_stream(
                &stream_config,
                move |data, _: &_| {
                    handle_samples::<f32>(
                        data,
                        &bus,
                        &alas_state,
                        &mut desire_to_broadcast,
                        &mut audio_last_seen,
                        audio_bus.as_mut()
                    )
                },
                err_fn,
                None
            ) {
                Ok(stream) => stream,
                Err(e) => {
                    eprintln!("Failed to build input stream: {}", e);
                    panic!("Failed to build input stream: {}", e);
                }
            };

        stream.play().expect("Could not play");
        println!("After play!");

        handler.block_on(async move {
            loop {
                select! {
                    message = exit_bus.recv() => {
                        match message {
                            Ok(AlasMessage::Exit) => {
                                return;
                            },
                            Err(e) => {
                                eprintln!("{:?}", e);
                                return;
                            }
                            _ => {}
                        }
                    }
                }
            }
        });
        println!("Received exit message in audio thread...");

        AudioThreads {
            config_thread,
            icecast,
            recording: record,
        }
    })
}
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

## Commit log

2024-12-19 Refactor to fix unit tests and clean up screen import cycles
    [audio.rs, main.rs]
2024-12-22 approximately the correct configuration for working audio
    [audio.rs]
2024-12-30 * Refactors on WiFi configuration situation * Fixes on the configuration menu
    [main.rs]
2024-12-31 Add cad files
    [Base.step, Face.step, Multipart.FCStd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]
2025-01-31 add throttle for voulme messages
2025-02-02 Enlarge pockets for buttons and LEDs on display, fix C14 size, fix height of base, improve the top
    [Base2.step, Face2.step, Multipart.FCStd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]
2025-03-03 made c14 slightly larger, adjusted thicknesses for new materials
    [Multipart.FCStd]
2025-03-03 new parts ordered, v3 confirmed
    [Bottom3.step, Face3.step, Multipart.FCStd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]
2025-03-12 Threading refactors and frontend progress
2025-03-14 A bunch of threading non-sense to allow for safe/clean exits
2025-03-15 Refactor, reformat, more threading, more more more
2025-03-15 Run CI on ARM to match Raspberry Pi
2025-03-23 Add "hole" for grounding stud
    [Multipart-Bottom.step, Multipart.FCStd]
2025-04-26 Add CM5 base board files, clean up CAD
    [Alas.FCStd, Base.step, Base2.step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]
2025-04-26 Latest Cm5 work
    [CM5IO.kicad_pcb, CM5IO.kicad_sch, CM5_GPIO.kicad_sch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]
2025-05-17 Make a ground plane (#4)
    * Way too much has changed...
    * things are still not connected
    * things are still not connected
    * new cm5 ordered!
    * 1. Fix hole size for JLCPCB limitations on testing
    2. Create fix_bom script which will correct the quantity and locations of the Raspberry Pi 5 Compute Module pins
    * Added screws and hardware to the face
    Imported new PCB as step (still need to redraw the standoffs)
    * Hopefully these are the corrected parts, need to cross-reference the BOM to what was ordered
    * Project clean up and WIP CAD model for enclosure
    * Uh in this version, I have made the 5v trace fatter
    * Delete some unnecessary components and fix up some of the trace thicknesses
    * Or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
    [Alas-Rack Face.step, Alas-Top.step, Alas.FCStd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]
2025-06-12 PCM1863 switchover (#5)
    * Oops, basically brand new ADC design using a new chip
    * Working PCB and working driver, sort of
    * --amend
    [BOM-CM5IO-fixed.csv, BOM-CM5IO.csv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]
2025-06-13 Ordered next round revision of sheet metal
    [Alas-Bottom.step, Alas-Rack Face.step, Alas-Top.step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]
2025-06-13 Fix the usb port (just in case) #1
    [CM5IO.kicad_pcb, CM5_HighSpeed.kicad_sch]
2025-07-16 Relatively final revision on the STEP files
    [Alas-Bottom.step, Alas-Rack Face.step, Alas-Top.step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]
2025-07-18 no private repo availability for arm runners
2025-07-18 Try pinning just version, print error on reboot/shutdown fail
2025-07-18 Try to pin just
2025-07-18 Dropbox button fix #10
    [audio.rs]
2025-07-23 Disable ipv6 on wwan (screws with routing) and make config.json flexible for eventual installation in /usr/bin (#15)
2025-07-23 idk what the hell happened here (#18)
    ### TL;DR
    Updated file paths to use `/var/lib/alas` directory and improved audio device selection to target PCM1863 hardware.
    ### What changed?
    - Changed configuration file path from `/etc/alas/config.json` to `/var/lib/alas/config.json`
    - Updated audio recording to save files to `/var/lib/alas/audio/` directory
    - Modified audio device selection to specifically target PCM1863 devices
    - Added error logging for JWT decoding failures
    - Updated Engarde client service configuration to use the new directory structure
    - Added user to audio group during setup
    - Changed redundancy manager paths to use the new directory structure
    - Modified Dropbox upload to gr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
    [audio.rs]
2025-07-23 State was behind held for too long, crashing the program (#21)
    Improved thread management for LCD display and fixed a potential deadlock in the Dropbox authentication flow.
    - Modified the LCD display thread to use `spawn_blocking` with a dedicated runtime instead of a regular tokio spawn
    - Fixed a potential deadlock in the Dropbox authentication flow by:
    - Reading the config under a read lock first
    - Only acquiring the write lock when actually updating the config
    ### How to test?
    1. Test the LCD display functionality to ensure it works properly with the new thread management
    2. Test the Dropbox authentication flow by:
    - Initiating a Dropbox link reques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
2025-07-26 Critical state fix plus unauthenticated nicety (#22)
    Improved error handling in both the backend audio connection and frontend API requests.
    - Fixed a potential deadlock in the Icecast connection logic by replacing `blocking_read()` with a non-blocking `try_read()` approach
    - Added comprehensive authentication error handling to the frontend API:
    - All API requests now check for 401/403 status codes
    - When authentication errors occur, users are automatically logged out and redirected to the login page
    - Added error handling for the audio meter EventSource to detect and handle authentication failures
    1. Test Icecast connection under high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
    [audio.rs]
2025-07-26 Fix default engarde configuration to exclude the wireguard interface (#23)
2026-01-10 Webhook claude (#25)
    * Webhook claude
    * try to build on pi natively
    * fix justfile?
    * args
    * Upload artifact
    * debug workflow
    * annoying
    * toolchain version
    * satisfy the build
    * continue to satisfy
    * ci fix?
    * let's try this
    * make a release build instead
    * let's try this
    [audio.rs, main.rs]
2026-04-05 WiFi, SSL, and static fixes
    [main.rs]

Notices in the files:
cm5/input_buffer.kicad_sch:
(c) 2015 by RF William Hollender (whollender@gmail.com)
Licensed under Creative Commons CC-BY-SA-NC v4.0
